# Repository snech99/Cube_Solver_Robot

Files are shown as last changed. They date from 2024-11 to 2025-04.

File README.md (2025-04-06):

# Cube_Solver_Robot

This work was created as part of a project in my mechatronics course at Hochschule Wismar, University of Applied Sciences: Technology, Business and Design. 
I worked on it together with a friend of mine. 

It's a Robot which can scan and solve a Rubik's Cube. It's possible to take out the Cube and twitch it by yourself. If you don't want to twist it by yourself, we have a mode which will turn it for you randomly with 20 moves. The Robot have two main modes: **Automatic and external_PC**.
Those modes are explained in a special PDF which you can find in the Repo.

The automatic mode solves the cube using an algorithm we wrote ourselves. It is based on the manual solution method, as a human would solve it.
This Code can be found under the following link: [Repo](https://github.com/snech99/Rubiks_Cube_Solver)

For external communication, the algorithm must be written by the user. There is a Python template for this, which communicates with the robot via a C program.
Download the folder /src/external_PC and compile the C program with make. You can then start the program as follows. You need the sudo privileges to be able to access the USB interface:

```bash
sudo ./main my_script
```

Here are some pictures to get an impression:

| Robot | Closeup of the colorsensor |
| --- | --- |
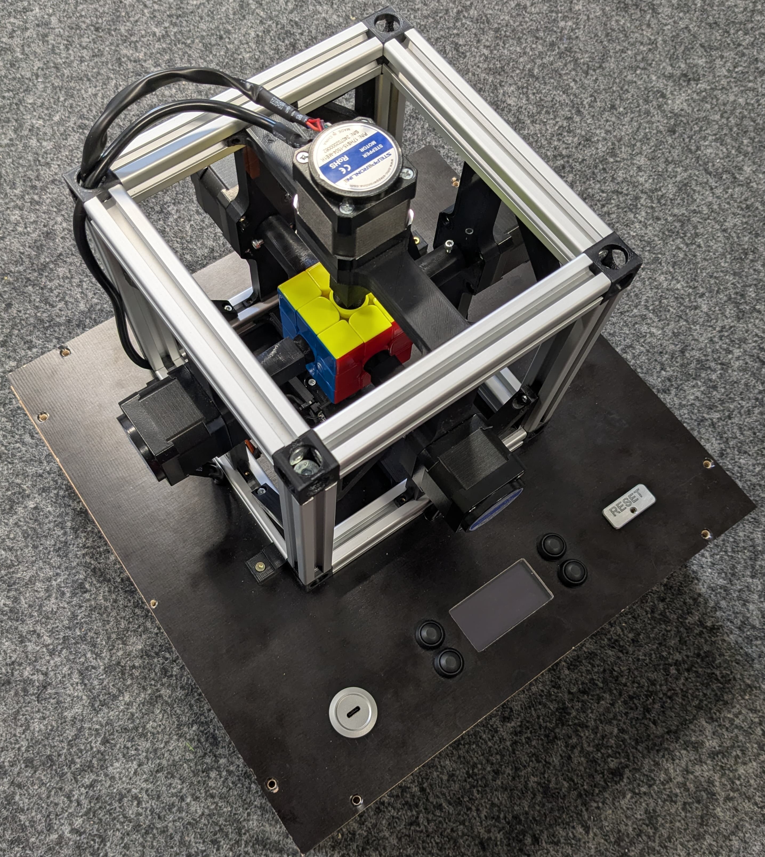
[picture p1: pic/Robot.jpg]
Robot
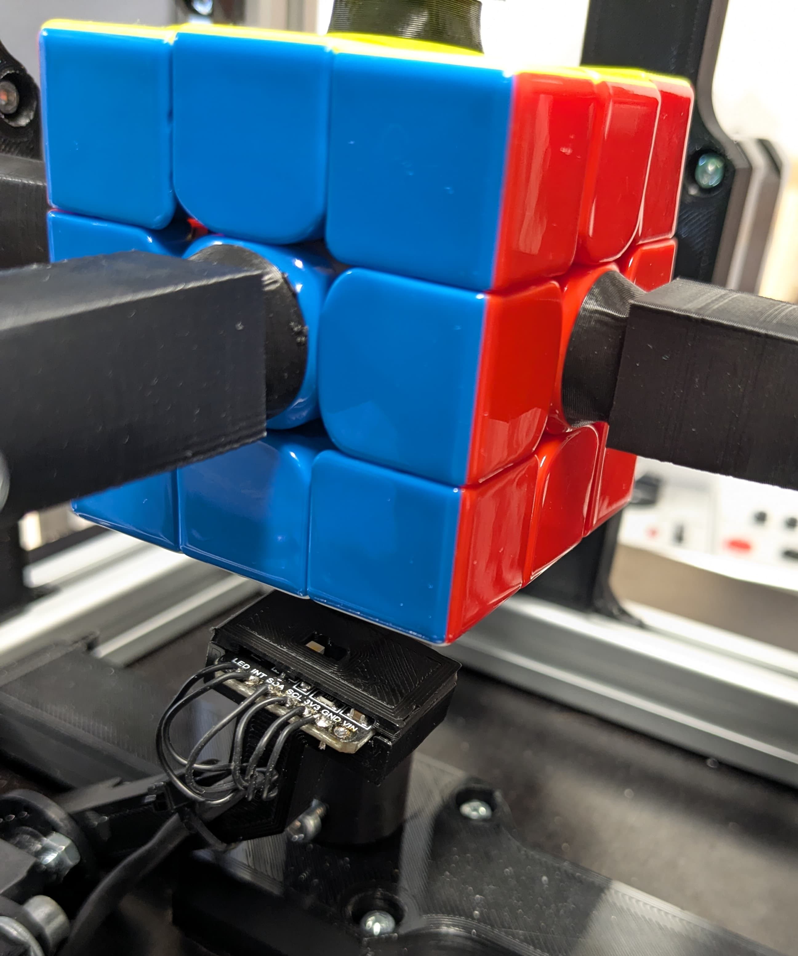
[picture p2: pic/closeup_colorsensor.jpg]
Closeup
|  |   |

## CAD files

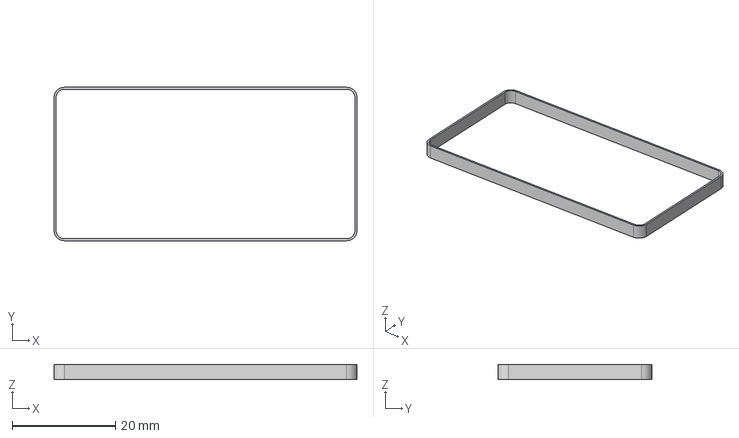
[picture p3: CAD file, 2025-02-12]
3D_Model/Einsatz Display v2.step
58.8 x 29.8 x 3.00 mm

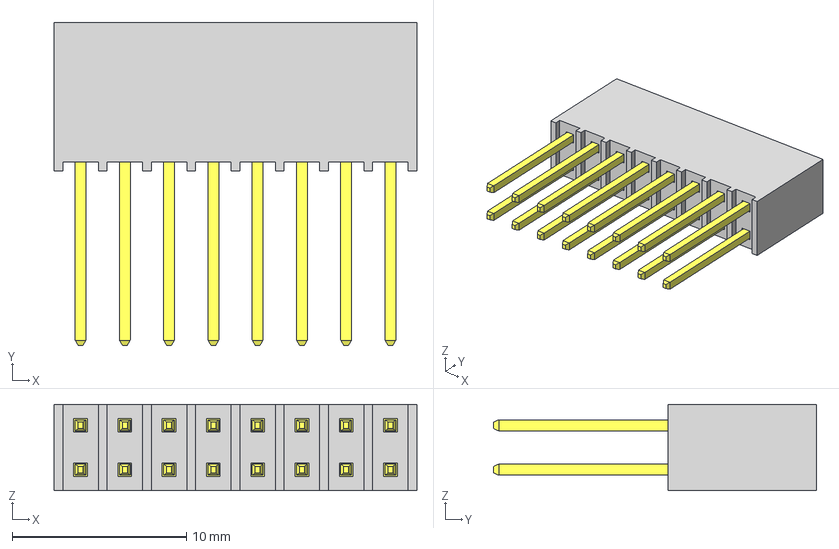
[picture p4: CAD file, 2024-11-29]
PCB/Solver_Shield/ALTIUM_EMBEDDED_MODELS/SSQ-108-03-T-D.stp
20.8 x 18.5 x 4.95 mm
T1SSQ-108-03-T-D
P2SSQ-108-03-T-D

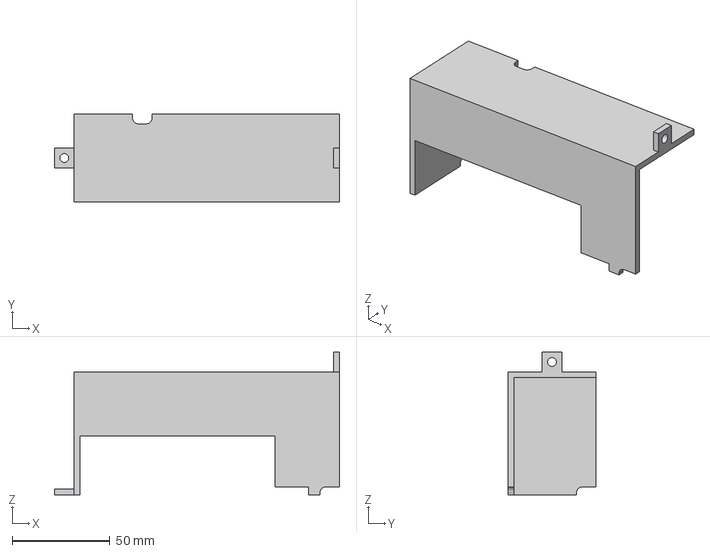
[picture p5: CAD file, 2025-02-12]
3D_Model/Abdeckung Netzteil klein v2.step
146.0 x 45.0 x 73.0 mm

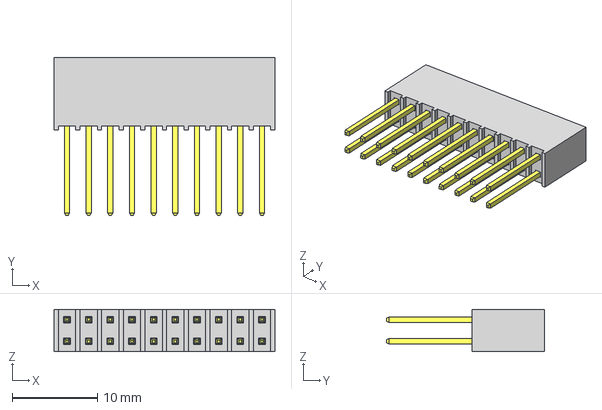
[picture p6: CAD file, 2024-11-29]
PCB/Solver_Shield/ALTIUM_EMBEDDED_MODELS/SSQ-110-03-T-D.stp
25.9 x 18.5 x 4.95 mm
T1SSQ-110-03-T-D
P2SSQ-110-03-T-D

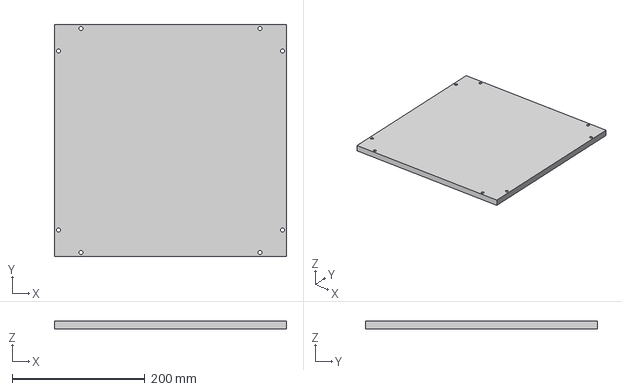
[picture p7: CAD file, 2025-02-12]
3D_Model/Boden v4.step
350.0 x 350.0 x 12.0 mm

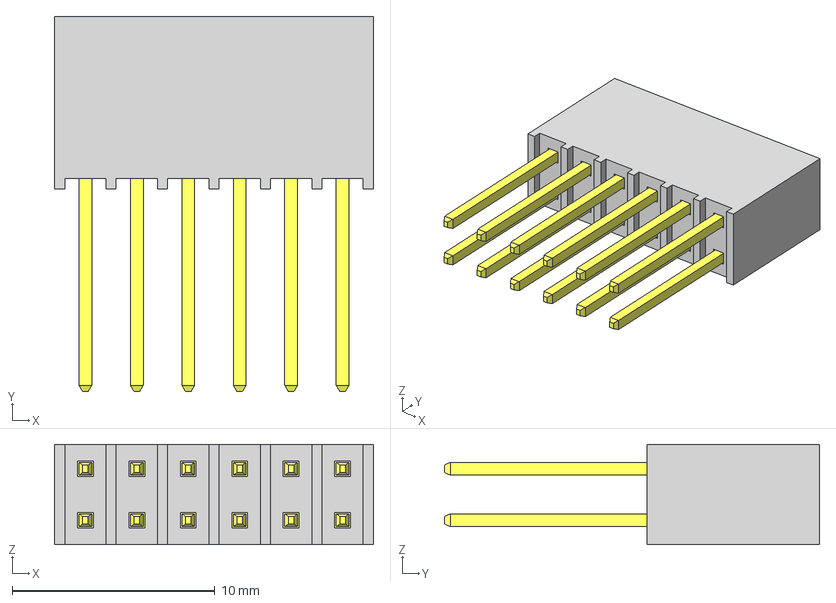
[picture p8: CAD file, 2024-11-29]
PCB/Solver_Shield/ALTIUM_EMBEDDED_MODELS/SSQ-106-03-T-D.stp
15.7 x 18.5 x 4.95 mm
T1SSQ-106-03-T-D
P2SSQ-106-03-T-D

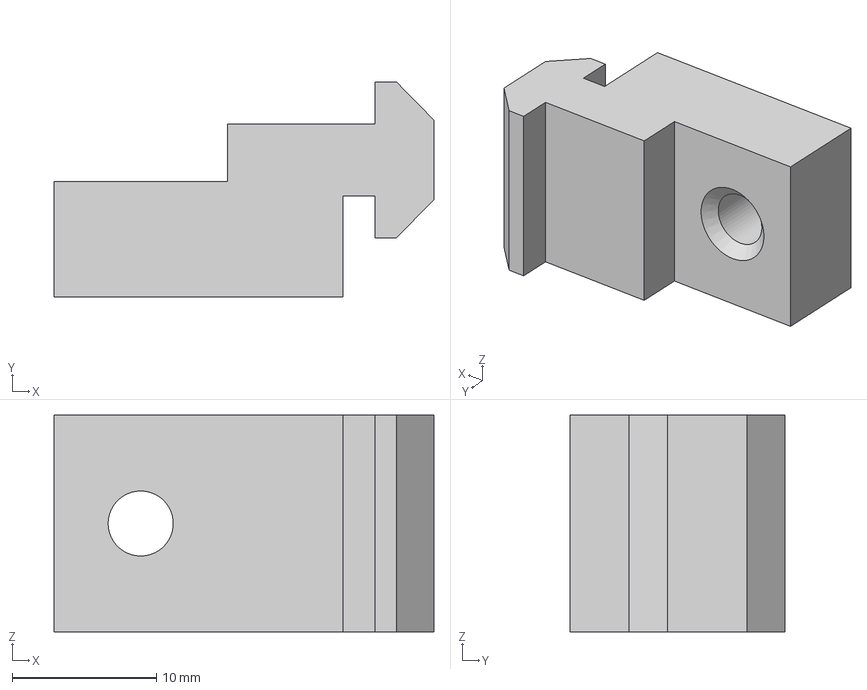
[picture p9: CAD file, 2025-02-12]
3D_Model/Halter Rahmen v5.step
26.3 x 14.9 x 15.0 mm

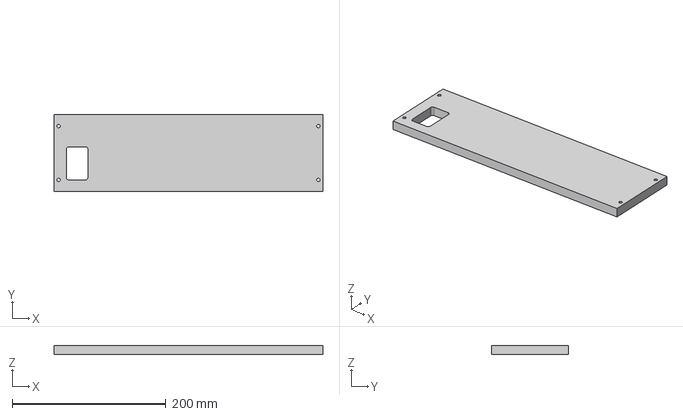
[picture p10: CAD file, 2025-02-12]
3D_Model/Wand hinten v6.step
350.0 x 100.0 x 12.0 mm

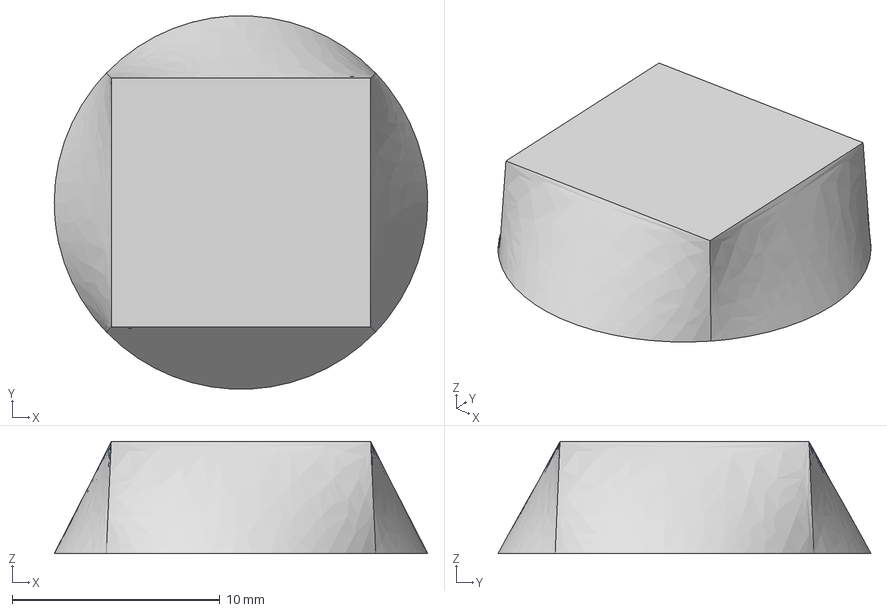
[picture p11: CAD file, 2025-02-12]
3D_Model/Halter Magnete Würfel v2.step
18.0 x 18.0 x 5.40 mm

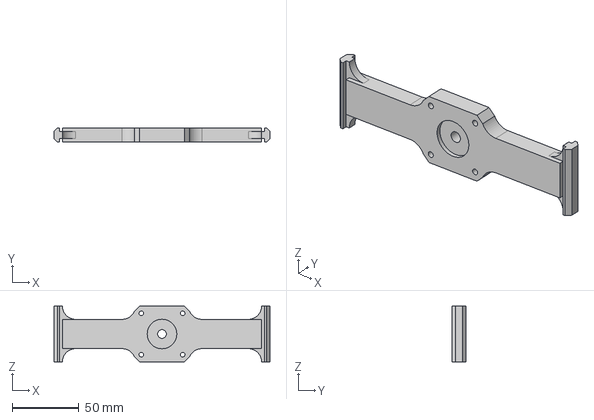
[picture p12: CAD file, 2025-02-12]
3D_Model/Halter Motor v26.step
162.2 x 10.8 x 42.0 mm

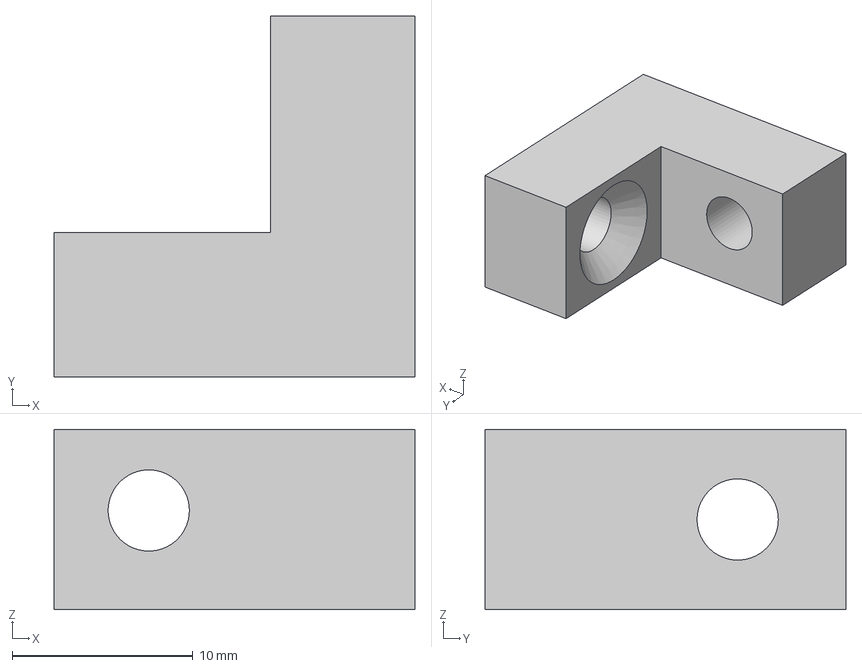
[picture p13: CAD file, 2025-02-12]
3D_Model/Halter Servo v4.step
20.0 x 20.0 x 10.0 mm

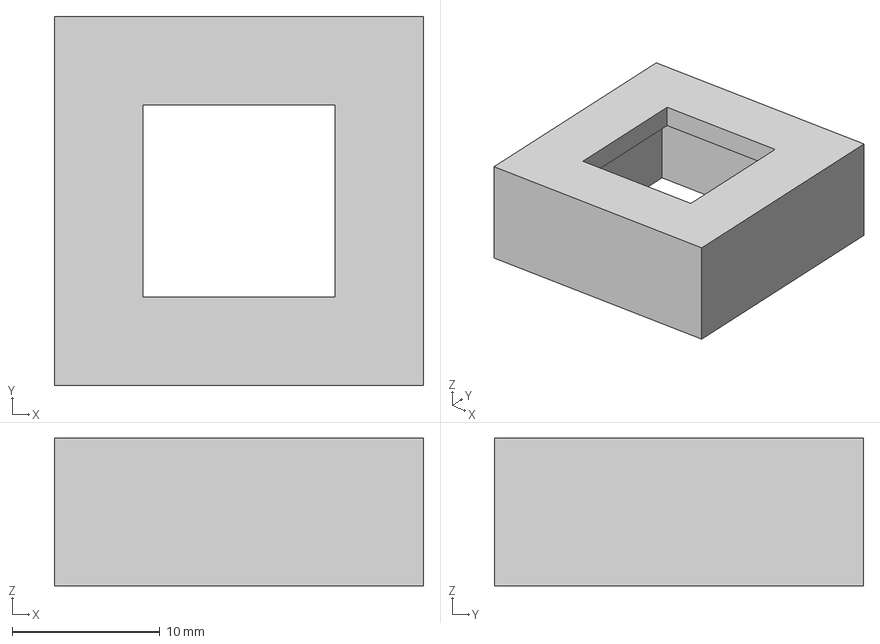
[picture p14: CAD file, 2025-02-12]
3D_Model/Klebehilfe Magnete v5.step
25.0 x 25.0 x 10.0 mm

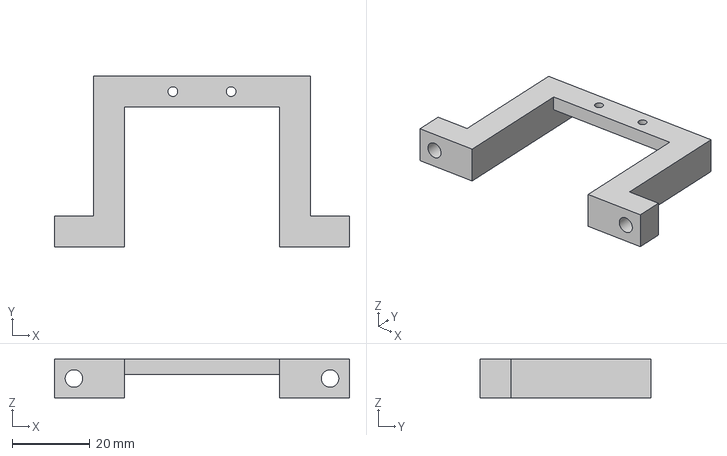
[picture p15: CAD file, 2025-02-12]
3D_Model/Halter USB v1.step
76.0 x 44.0 x 10.0 mm

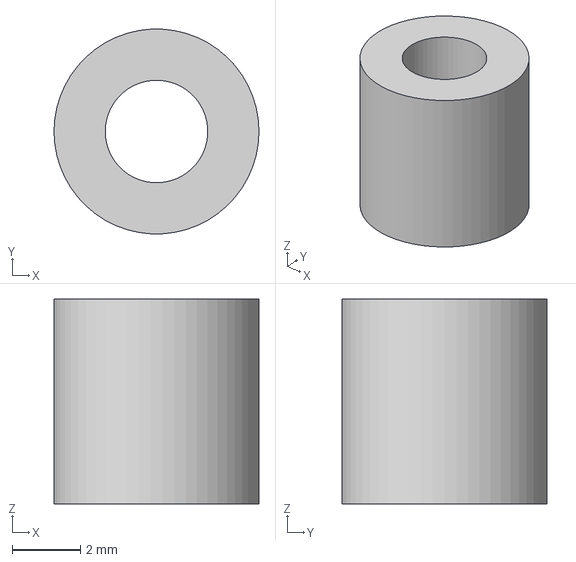
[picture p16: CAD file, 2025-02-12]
3D_Model/Abstandshalter Stepdownwandler v2.step
6.00 x 5.99 x 6.00 mm

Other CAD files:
3D_Model/Deckel v22.step
3D_Model/Deckel ohne USB v4.step
3D_Model/Wand vorne v4.step
3D_Model/Halter Magnete v10.step
3D_Model/Abdeckung Netzteil v5.step
3D_Model/Abdeckung Sensor v7.step
3D_Model/Abstandshalter Display v2.step
3D_Model/Ecke Aluprofil v8.step
3D_Model/Halter Reset v3.step
3D_Model/Halter Reset v4.step
3D_Model/Reset Griff v1.step
3D_Model/Schild v3.step
3D_Model/Sensorarm v34.step
3D_Model/Versteifung v2.step
3D_Model/Wand links_rechts v6.step

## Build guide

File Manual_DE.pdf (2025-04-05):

# Manual Cube_Solver_Robot

## Inhalt

## Hardware

- Sechs Schrittmotoren im Closed-Loop System: Nema 17HS15-1504-ME1K
- Sechs Closed-Loop Schrittmotortreiber: CL42T-V41
- Servo Motor: RS2
- FRDM-MCXA153 Development Board (MCUXpresso IDE)
- Farbsensor: TCS34725 RGB
- Würfel: QiYi M Pro 3x3 MagLev Ball-Core UV Coated (Achtung nicht jeder Würfel ist geeignet)
- OLED-Bildschirm: SSD1309
- 5 Taster
- Netzteil 24V: S-250-25
- Stepdown-Wandler: LM2596 (für Lüfter)
- Stepdown-Wandler: ICQUANZX DC DC 9A 300W (für 5V Netz)
- 4 Lüfter: SUN MF80252V3-1
- 48 Neodym 5x5x5mm
- Selbstentwickelte Platine
- USB-C Buchse und Konverter: CP2102
- Kaltgeräte Buchse und Kabel: 693-4302.2001

## Würfel tauschen

Der Würfel ist über Magnete mit den Motoren verbunden. Dafür muss dieser jedoch leicht modifiziert werden, dafür wurden an jeder Seite des Würfels vier kleine Magnete verklebt. Dabei ist die Ausrichtung der Magnete zu beachten. Sie sind alle in einem Nord-Süd Wechsel angebracht. Dies ist ebenfalls beim Einbauen des Würfels zu beachten und es müssen ggf. Motoren um 90° gedreht werden, damit die Magnete des Würfels und der Motoren passend übereinstimmen.

ACHTUNG:
Beim Einsetzten MUSS die Gelbe Fläche nach oben und die Rote Fläche nach vorne zeigen!

Der Würfel ist frei entnehmbar und sollte entweder vor dem Anschalten des Roboters eingesetzt werden oder in dem dafür vorgesehenen Modus: „Change Cube“.

Wichtig ist, dass sich der Roboter nach dem Einschalten und in dem oben genannten Modus kalibriert. Daher ist es wichtig, dass der Würfel annähernd passend und nicht verkanntet eingesetzt wird.

## Reset

Falls sich der Roboter aufhängen sollte gibt es auch einen Reset Knopf, welcher mit einem passenden Stift betätigt werden kann. Auch hier wird sich der Roboter neu kalibrieren. Außerdem wird der Kontroller zurückgesetzt und verliert jegliche gespeicherte Informationen.

## Zustands Automat

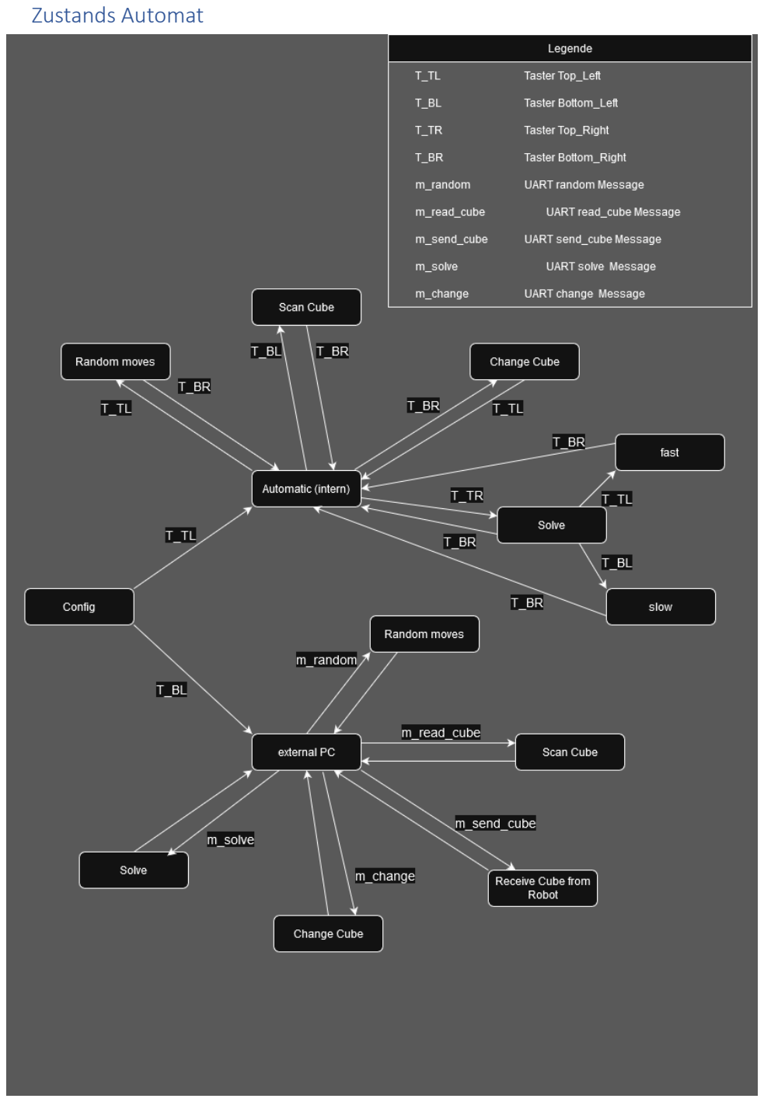
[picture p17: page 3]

## Allgemeine Funktionen und Modi

Der Roboter verfügt über zwei Hauptmodi: Automatic und external_PC

Die Funktionen des Roboters sind dabei sehr ähnlich, jedoch ändert sich die Bedienung. In dem Automatic- Modus wird der Roboter über vier Taster und den Bildschirm gesteuert. Bei dem external_PC- Modus läuft diese Bedienung über die USB-Schnittstelle. Diese Auswahl muss nach dem Anschalten des Roboters über Taster ausgewählt werden. Für den external_PC-Modus existiert im /src/external_Computer Ordner eine Datei für die Kommunikation.

### Funktionen im Automatic-Modus

Random moves
In dieser Funktion verdreht der Roboter zufällig 20 Seiten nacheinander. Der „Zufall“ wird hier über eine interne rand() Funktion gelöst, welchen den aktuellen Systemtick des Kontrollers als Seed nutzt.

Change Cube
Hier werden alle Motoren deaktiviert und der Würfel kann entnommen und/oder eingesetzt werden.

Nach dem Tauschen muss ein Taster auf dem Roboter gedrückt werden, um den Wechsel zu bestätigen. Im Folgenden kalibrieren sich alle Seiten wieder nacheinander und der Roboter ist erneut einsatzbereit.

Scan Cube
In dieser Funktion wird der Würfel eingelesen. Dafür wird jede Fläche nacheinander von einem Farbsensor gelesen dann interpretiert und abgespeichert. Um alle Flächen auf die untere Seite zu bekommen wird eine bestimmte Zugabfolge genutzt, welche den Würfel nicht verändert. Somit ist am Ende nach ca. 35 Sekunden der gesamte Würfel eingelesen und wurde dennoch nicht verändert.

Die einzelnen Steine werden nach einem bestimmten System in einem Array abgespeichert, welches später genauer erläutert wird.

Solve
Hier löst ein von uns selbst geschriebener Algorithmus den eingelesenen Würfel und speichert die benötigten Züge in ein Array auf dem Kontroller ab. Dieser Algorithmus ist auf der GitHub Seite des Repo verlinkt.

Fast/Slow
In diesen Funktionen wird das in Solve berechnete Lösungsarray mit der entsprechenden Geschwindigkeit ausgeführt. Nach dem Erfolgreichen Lösen des Würfels werden die benötigten Züge und Zeit auf dem Bildschirm angezeigt.

### Funktionen im external_PC-Modus

Random moves
In dieser Funktion verdreht der Roboter zufällig 20 Seiten nacheinander. Der „Zufall“ wird hier über eine interne rand() Funktion gelöst, welchen den aktuellen Systemtick des Kontrollers als Seed nutzt.

Change Cube
Hier werden alle Motoren deaktiviert und der Würfel kann entnommen und/oder eingesetzt werden.

Nach dem Tauschen muss ein Taster auf dem Roboter gedrückt werden, um den Wechsel zu bestätigen. Im Folgenden kalibrieren sich alle Seiten wieder nacheinander und der Roboter ist wieder einsatzbereit.

Scan Cube
In dieser Funktion wird der Würfel eingelesen. Dafür wird jede Fläche nacheinander von einem Farbsensor gelesen dann interpretiert und abgespeichert. Um alle Flächen auf die untere Seite zu bekommen wird eine bestimmte Zugabfolge genutzt, welche den Würfel nicht verändert. Somit ist am Ende nach ca. 35 Sekunden der gesamte Würfel eingelesen und wurde dennoch nicht verändert.

Die einzelnen Steine werden nach einem bestimmten System in einem Array abgespeichert, welches später genauer erläutert wird.

Receive Cube from Robot
Hier wird der eingelesene Würfel vom Roboter über die USB-Schnittstelle an den externen PC gesendet und dort abgespeichert.

Wichtig: In den externen Bedienoptionen gibt es noch zwei weitere Funktionen, welche nicht auf dem Bild des Zustands Automaten oben aufgeführt sind.

Show Cube

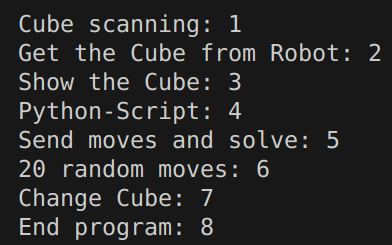
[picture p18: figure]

In dieser Funktion wird der zuletzt Empfangene Würfen im Terminal ausgegeben.

Python-Skript
Hier wird vom C Programm über die Funktion fork() ein Python-Skript ausgeführt. Dieses berechnet dann die benötigten Züge, um den Würfel zu lösen. Die Kommunikation zwischen dem C Programm und dem Python Skript wird über Inter-Prozess-Communication (IPC) realisiert.

Passend dafür existiert im /src/external_Computer Ordner eine Vorlage in welcher nur noch der eigene Lösungsalgorithmus implementiert werden muss. In dieser Vorlage wird der Würfel aus dem C Programm eingelesen und am Ende das Lösungsarray mit maximal 1024 Züge zurück an das C Programm gesendet.

Solve
In dieser Funktion wird das aus dem Python-Skript berechnete Lösungsarray an den Kontroller geschickt und dort auch sofort ausgeführt. Am Ende werden die benötigten Züge und die Zeit auf dem Bildschirm angezeigt.

## Darstellung des Würfels für den external_PC-Modus

Jede Farbe ist einer Zahl zugeordnet:

Das eingelesene Array besteht aus 54 Zahlen und jede repräsentiert eine farbige Seite eines Steins auf dem Würfel. Das Array besteht so theoretisch aus 6 Blöcken, welche jeweils eine Fläche darstellen. Jeder dieser Blöcke beinhaltet 9 Zahlen. Die Reihenfolge der eingelesenen Blöcke ist:

Weiß -> Rot -> Blau-> Orange -> Grün -> Gelb

Jeder Stein auf dieser Fläche wird dabei nach dem folgenden Muster eingelesen:

Farbe | Nummer
Weiß | 1
Gelb | 2
Rot | 3
Grün | 4
Orange | 5
Blau | 6

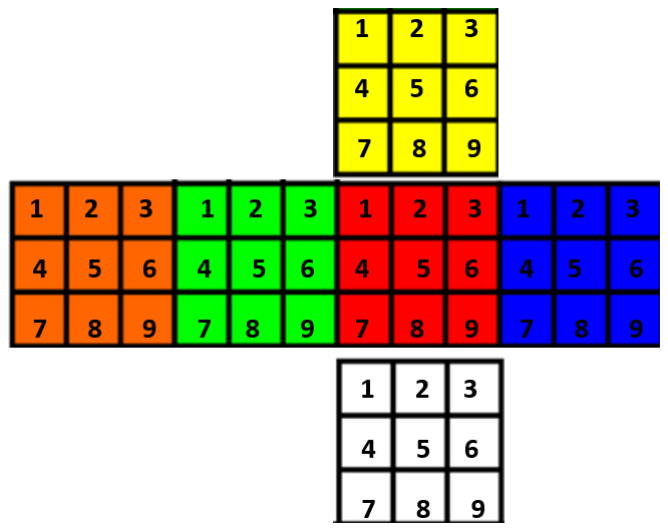
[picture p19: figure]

Würfel = [

W1, W2, W3, W4, W5, W6, W7, W8, W9,

R1, R2, R3, R4, R5, R6, R7, R8, R9,

B1, B2, B3, B4, B5, B6, B7, B8, B9,

O1, O2, O3, O4, O5, O6, O7, O8, O9,

G1, G2, G3, G4, G5, G6, G7, G8, G9,

Y1, Y2, Y3, Y4, Y5, Y6, Y7, Y8, Y9

]

Tipp: Die Zahlen an der Position 5 des Blockes repräsentieren die Farbe der Fläche, da sich die Mittelsteine nicht verschieben lassen!

## Darstellung der Drehungen für den external_PC-Modus

Jede Drehung ist mit folgenden Zahlen codiert (Genormte Notation als Vergleich).

Rechts beschreibt die Drehung im Uhrzeigersinn und Links die gegen den Uhrzeigersinn.

Das Ergebnisarray, welches an den Roboter geschickt wird, darf somit nur Zahlen zwischen 1 und 12 oder 21 und 26 beinhalten. Außerdem ist die Länge auf 1024 Züge begrenzt.

## Software

Für Änderungen in der Software ist der Code für den Mikrocontroller ebenfalls mit im Repo. Zu beachten sind hier die #defines in der Cube_Project.h, welche für den jeweils verwendetet Roboter einzustellen sind, da sich die beiden Modelle doch etwas unterscheiden.

Diese Unterschiede sind in der Kalibrierung der Achsen und des Farbsensors zu beachten und gegebenenfalls anzupassen.

Seite | Rechts | Links | Doppel | Notation
Weiß | 1 | D | 7 | D‘ | 21 | D2 | Down
Gelb | 2 | U | 8 | U‘ | 22 | U2 | Up
Rot | 3 | F | 9 | F‘ | 23 | F2 | Front
Grün | 4 | R | 10 | R‘ | 24 | R2 | Right
Orange | 5 | B | 11 | B‘ | 25 | B2 | Back
Blau | 6 | L | 12 | L‘ | 26 | L2 | Left

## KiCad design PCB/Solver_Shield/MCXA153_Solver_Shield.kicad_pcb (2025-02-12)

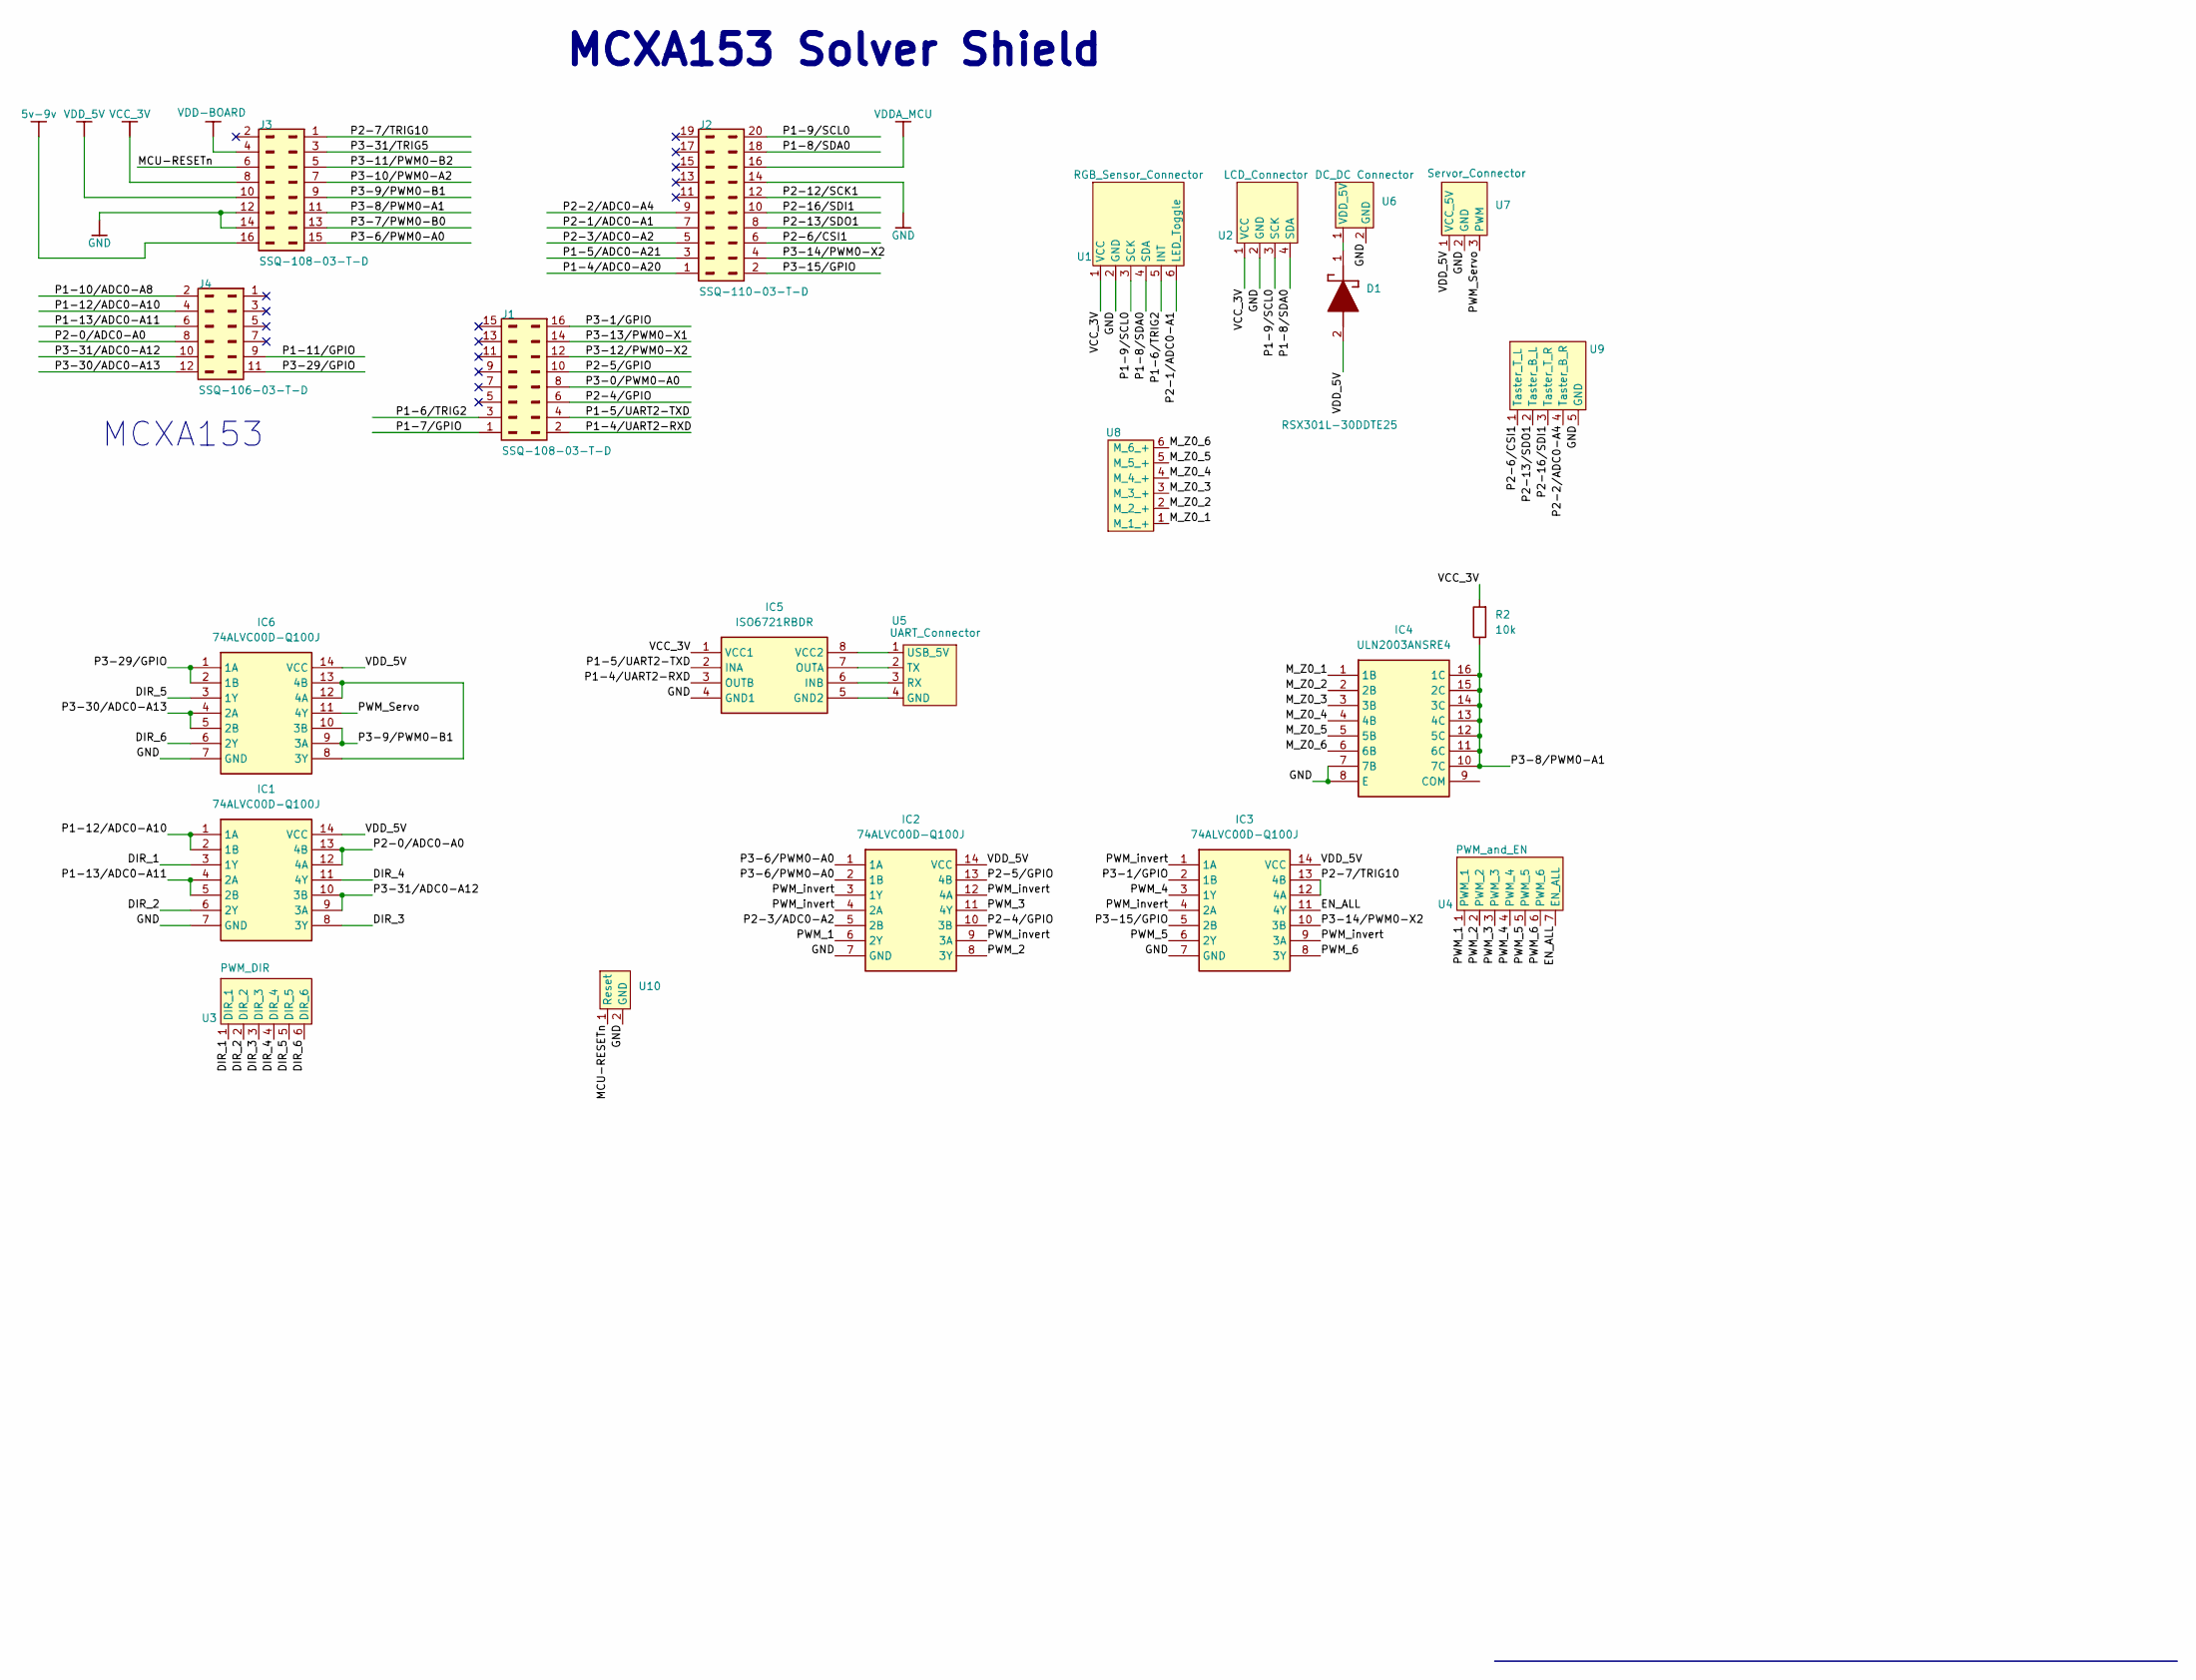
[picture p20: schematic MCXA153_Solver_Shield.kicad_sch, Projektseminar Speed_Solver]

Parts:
D1: RSX301L-30DDTE25; DIOM5026X220N; Mouser Part Number 755-RSX301L-30DDTE25
IC1, IC2, IC3, IC6: 74ALVC00D-Q100J; SOIC127P600X175-14N; Mouser Part Number 771-74ALVC00DQ100J
IC4: ULN2003ANSRE4; SOIC127P780X200-16N; Mouser Part Number 595-ULN2003ANSRE4
IC5: ISO6721RBDR; SOIC127P600X175-8N; Mouser Part Number 595-ISO6721RBDR
J1, J3: SSQ-108-03-T-D; MANUFACTURER PART NUMBER SSQ-108-03-T-D
J2: SSQ-110-03-T-D; MANUFACTURER PART NUMBER SSQ-110-03-T-D
J4: SSQ-106-03-T-D; MANUFACTURER PART NUMBER SSQ-106-03-T-D
R2: 10k; R_0603_1608Metric_Pad0.98x0.95mm_HandSolder
U1: Pinheader_Sensor
U2: Pinheader_LCD
U3: PWM_DIR
U4: Treiber_PWM
U5: UART
U6: VDD_5V
U7: Servo
U8: Z0
U9: Taster
U10: Reset_Connector

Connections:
5v-9v: J3.16
/DIR_1: IC1.3 (1Y), U3.1 (DIR)
/DIR_2: IC1.6 (2Y), U3.2 (DIR)
/DIR_3: IC1.8 (3Y), U3.3 (DIR)
/DIR_4: IC1.11 (4Y), U3.4 (DIR)
/DIR_5: IC6.3 (1Y), U3.5 (DIR)
/DIR_6: IC6.6 (2Y), U3.6 (DIR)
/EN_ALL: IC3.11 (4Y), U4.7 (EN_ALL)
/MCU-RESETn: J3.6, U10.1 (Reset)
/M_Z0_1: IC4.1 (1B), U8.1 (M_1_+)
/M_Z0_2: IC4.2 (2B), U8.2 (M_2_+)
/M_Z0_3: IC4.3 (3B), U8.3 (M_3_+)
/M_Z0_4: IC4.4 (4B), U8.4 (M_4_+)
/M_Z0_5: IC4.5 (5B), U8.5 (M_5_+)
/M_Z0_6: IC4.6 (6B), U8.6 (M_6_+)
/P1-4/ADC0-A20: J2.1
/P1-4/UART2-RXD: IC5.3 (OUTB), J1.2
/P1-5/ADC0-A21: J2.3
/P1-5/UART2-TXD: IC5.2 (INA), J1.4
/P1-6/TRIG2: J1.3, U1.5 (INT)
/P1-7/GPIO: J1.1
/P1-8/SDA0: J2.18, U1.4 (SDA), U2.4 (SDA)
/P1-9/SCL0: J2.20, U1.3 (SCK), U2.3 (SCK)
/P1-10/ADC0-A8: J4.2
/P1-11/GPIO: J4.9
/P1-12/ADC0-A10: IC1.1 (1A), IC1.2 (1B), J4.4
/P1-13/ADC0-A11: IC1.4 (2A), IC1.5 (2B), J4.6
/P2-0/ADC0-A0: IC1.12 (4A), IC1.13 (4B), J4.8
/P2-1/ADC0-A1: J2.7, U1.6 (LED_Toggle)
/P2-2/ADC0-A4: J2.9, U9.4 (Taster_B_R)
/P2-3/ADC0-A2: IC2.5 (2B), J2.5
/P2-4/GPIO: IC2.10 (3B), J1.6
/P2-5/GPIO: IC2.13 (4B), J1.10
/P2-6/CSI1: J2.6, U9.1 (Taster_T_L)
/P2-7/TRIG10: IC3.12 (4A), IC3.13 (4B), J3.1
/P2-12/SCK1: J2.12
/P2-13/SDO1: J2.8, U9.2 (Taster_B_L)
/P2-16/SDI1: J2.10, U9.3 (Taster_T_R)
/P3-0/PWM0-A0: J1.8
/P3-1/GPIO: IC3.2 (1B), J1.16
/P3-6/PWM0-A0: IC2.1 (1A), IC2.2 (1B), J3.15
/P3-7/PWM0-B0: J3.13
/P3-8/PWM0-A1: IC4.10 (7C), IC4.11 (6C), IC4.12 (5C), IC4.13 (4C), IC4.14 (3C), IC4.15 (2C), IC4.16 (1C), J3.11, R2.1
/P3-9/PWM0-B1: IC6.9 (3A), IC6.10 (3B), J3.9
/P3-10/PWM0-A2: J3.7
/P3-11/PWM0-B2: J3.5
/P3-12/PWM0-X2: J1.12
/P3-13/PWM0-X1: J1.14
/P3-14/PWM0-X2: IC3.10 (3B), J2.4
/P3-15/GPIO: IC3.5 (2B), J2.2
/P3-29/GPIO: IC6.1 (1A), IC6.2 (1B), J4.11
/P3-30/ADC0-A13: IC6.4 (2A), IC6.5 (2B), J4.12
/P3-31/ADC0-A12: IC1.9 (3A), IC1.10 (3B), J4.10
/P3-31/TRIG5: J3.3
/PWM_1: IC2.6 (2Y), U4.1 (PWM_1)
/PWM_2: IC2.8 (3Y), U4.2 (PWM_2)
/PWM_3: IC2.11 (4Y), U4.3 (PWM_3)
/PWM_4: IC3.3 (1Y), U4.4 (PWM_4)
/PWM_5: IC3.6 (2Y), U4.5 (PWM_5)
/PWM_6: IC3.8 (3Y), U4.6 (PWM_6)
/PWM_Servo: IC6.11 (4Y), U7.3 (PWM)
/PWM_invert: IC2.3 (1Y), IC2.4 (2A), IC2.9 (3A), IC2.12 (4A), IC3.1 (1A), IC3.4 (2A), IC3.9 (3A)
GND: IC1.7 (GND), IC2.7 (GND), IC3.7 (GND), IC4.7 (7B), IC4.8 (E), IC5.4 (GND1), IC6.7 (GND), J2.14, J3.12, J3.14, U1.2 (GND), U2.2 (GND), U6.2 (GND), U7.2 (GND), U9.5 (GND), U10.2 (GND)
unnamed: D1.1 (K), U6.1 (VDD_5V)
unnamed: IC5.5 (GND2), U5.4 (GND)
unnamed: IC5.6 (INB), U5.3 (RX)
unnamed: IC5.7 (OUTA), U5.2 (TX)
unnamed: IC5.8 (VCC2), U5.1 (USB_5V)
unnamed: IC6.8 (3Y), IC6.12 (4A), IC6.13 (4B)
VCC_3V: IC5.1 (VCC1), J3.8, R2.2, U1.1 (VCC), U2.1 (VCC)
VDD-BOARD: J3.4
VDDA_MCU: J2.16
VDD_5V: D1.2 (A), IC1.14 (VCC), IC2.14 (VCC), IC3.14 (VCC), IC6.14 (VCC), J3.10, U7.1 (VCC_5V)

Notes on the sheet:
MCXA153 Solver Shield
MCXA153

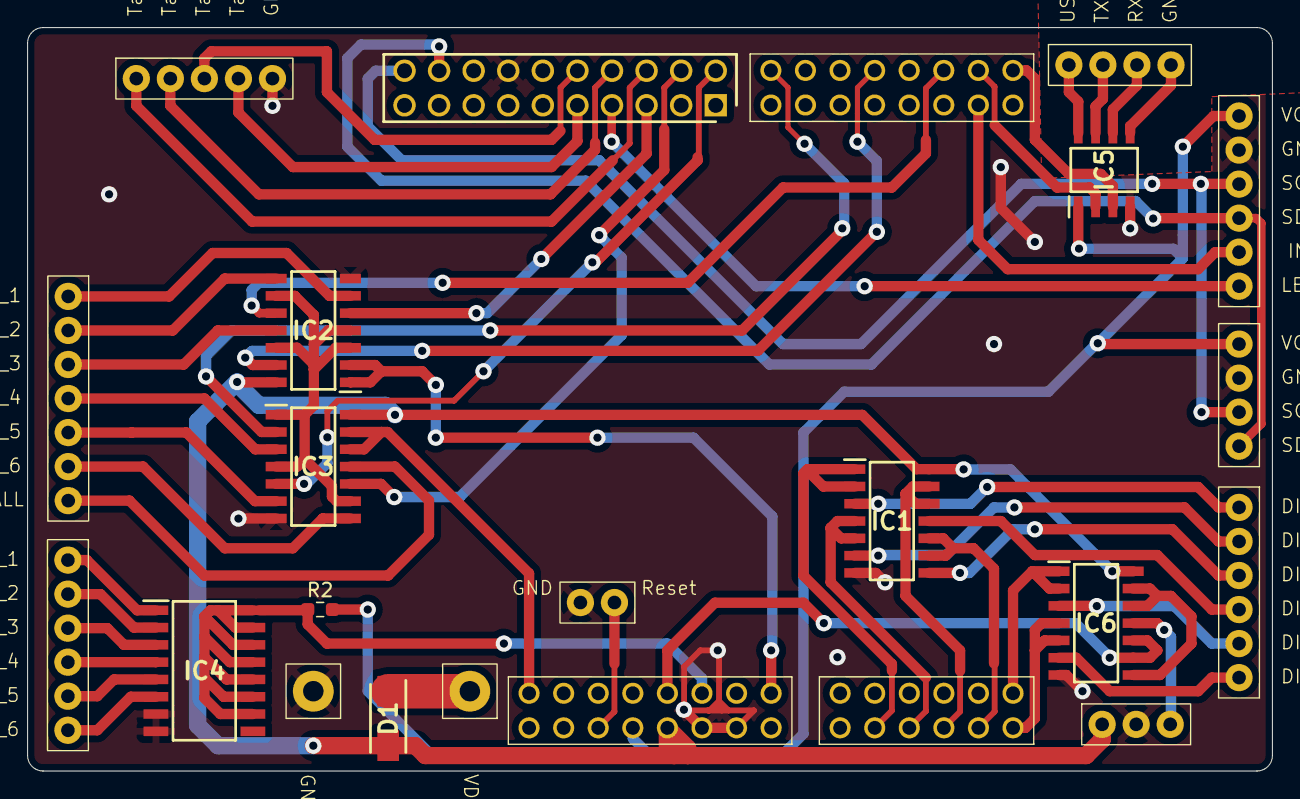
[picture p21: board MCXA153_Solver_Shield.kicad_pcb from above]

Board: 2 copper layers, 91.4 x 54.6 mm, 22 parts (0 on the bottom side), 57 nets.

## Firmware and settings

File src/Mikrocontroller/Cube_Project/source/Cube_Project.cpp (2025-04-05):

/*
*   Gerrit Hinrichs 01.2025
*   github.com/snech99
*
*   Cube_Solver_Robot
*   main file for the Controller with super-loop
*/
#include <stdio.h>
#include <stdlib.h>
#include "board.h"
#include "clock_config.h"
#include "MCXA153.h"

#include "Cube_Project.h"
#include "state_machine.h"

uint8_t rx_buffer[BUFFER_MAX] = {};
uint16_t rx_buffer_index = 0;

bool flag_hit_1 = false;
bool flag_hit_2 = false;
bool SW_hit_flag = false;
bool SW_flag_TL = false;
bool SW_flag_TR = false;
bool SW_flag_BL = false;
bool SW_flag_BR = false;
bool color_busy_flag = true;
bool pwm_busy_flag = false;
bool pwm_servo_busy_flag = false;
bool NULL_flag = false;

uint32_t tick_count = 0;
uint32_t tick_start = 0;
uint32_t tick_end = 0;

volatile uint32_t pwm_ms_count = 0;
volatile int32_t PWM_flanke_count = 250;
volatile uint32_t PWM_frequenz = PWM_FREQUENZ;
volatile uint32_t PWM_ramp_time = RAMP_LONG;

// Timer for PWM-Ramp
void TIMER1_CALLBACK_RAMPE(uint32_t flags)
{
	if (pwm_ms_count < (PWM_ramp_time-1))
	{
		float add_frequenz = (float)PWM_frequenz/PWM_ramp_time;
		uint32_t new_frequenz = (uint32_t) add_frequenz + (pwm_ms_count*add_frequenz);

		if(new_frequenz == 0)
		{
			new_frequenz = 1;
		}
		pwm_ms_count++;

		PWM_SetupPwm(FLEXPWM0_PERIPHERAL, FLEXPWM0_ALL_PWM, FLEXPWM0_ALL_PWM_pwm_function_config, 1U, kPWM_SignedCenterAligned,
				new_frequenz, FLEXPWM0_ALL_PWM_SM_CLK_SOURCE_FREQ_HZ);

		FLEXPWM0_PERIPHERAL->MCTRL |= PWM_MCTRL_LDOK(kPWM_Control_Module_0);
	}
	else
	{
		if(PWM_frequenz == 0)
		{
			PWM_frequenz = 1;
		}

		PWM_SetupPwm(FLEXPWM0_PERIPHERAL, FLEXPWM0_ALL_PWM, FLEXPWM0_ALL_PWM_pwm_function_config, 1U, kPWM_SignedCenterAligned,
				PWM_frequenz, FLEXPWM0_ALL_PWM_SM_CLK_SOURCE_FREQ_HZ);


		FLEXPWM0_PERIPHERAL->MCTRL |= PWM_MCTRL_LDOK(kPWM_Control_Module_0);
		CTIMER_StopTimer(CTIMER1);
	}
}

// Timer to debounce the buttons
void TIMER0_ISR_RESET_CALLBACK(uint32_t flags)
{
	if(GPIO_PinRead(GPIO2, TASTER_T_L) == 0)
	{
		SW_flag_TL = true;
	}

	if(GPIO_PinRead(GPIO2, TASTER_T_R) == 0)
	{
		SW_flag_TR = true;
	}

	if(GPIO_PinRead(GPIO2, TASTER_B_L) == 0)
	{
		SW_flag_BL = true;
	}

	if(GPIO_PinRead(GPIO2, TASTER_B_R) == 0)
	{
		SW_flag_BR = true;
	}

	GPIO_GpioClearInterruptFlags(GPIO2, 1<<TASTER_T_L);
	GPIO_GpioClearInterruptFlags(GPIO2, 1<<TASTER_T_R);
	GPIO_GpioClearInterruptFlags(GPIO2, 1<<TASTER_B_L);
	GPIO_GpioClearInterruptFlags(GPIO2, 1<<TASTER_B_R);

	CTIMER_StopTimer(CTIMER0);
	EnableIRQ(GPIO2_IRQN);
}

// General delay Timer
void Busy_Timer(uint32_t flags)
{
	pwm_servo_busy_flag = false;
	pwm_busy_flag = false;
}

/* FLEXPWM0_SUBMODULE0_IRQn interrupt handler */
extern "C" void INTERRUPT_PWM(void)
{
	if (PWM_GetStatusFlags(FLEXPWM0_PERIPHERAL, kPWM_Module_0) & kPWM_CompareVal2Flag)
	{
		PWM_flanke_count--;
		if(PWM_flanke_count <= 0)
		{
			FLEXPWM0_PERIPHERAL->MCTRL &= ~(PWM_MCTRL_RUN(kPWM_Control_Module_0));
			CTIMER_StartTimer(CTIMER2);
		}
	}
	PWM_ClearStatusFlags(FLEXPWM0_PERIPHERAL, kPWM_Module_0, kPWM_CompareVal2Flag);
}


/* LPUART0_IRQn interrupt handler */
extern "C" void LPUART2_SERIAL_RX_TX_IRQHANDLER(void)
{
	uint8_t data;
	uint32_t status= LPUART_GetStatusFlags(LPUART2_PERIPHERAL);

	if ( (status & kLPUART_RxDataRegFullFlag) )
	{
		data = LPUART_ReadByte(LPUART2_PERIPHERAL);

		if(rx_buffer_index < BUFFER_MAX)
		{
			rx_buffer[rx_buffer_index] = data;
			rx_buffer_index ++;
		}
		else
		{
			GPIO_PinWrite(BOARD_LED_RED_GPIO, 12, 0);
			GPIO_PinWrite(BOARD_LED_GREEN_GPIO, 13, 1);
			GPIO_PinWrite(BOARD_LED_BLUE_GPIO, 0, 0);
		}

		if(data == '$')
		{
			flag_hit_1 = true;
		}

		if((data == '%') && flag_hit_1)
		{
			flag_hit_2 = true;
		}
	}
	LPUART_ClearStatusFlags(LPUART2_PERIPHERAL, kLPUART_RxDataRegFullFlag);
}

/* GPIO1_IRQn interrupt handler */
extern "C" void GPIO1_IRQHANDLER(void)
{
	uint32_t hit_flag = GPIO_GpioGetInterruptFlags(GPIO1);

	if((hit_flag>>INTERUPT_SENSOR_PIN) == 1)
	{
		color_busy_flag = false;
	}

	GPIO_GpioClearInterruptFlags(GPIO1, 1<<INTERUPT_SENSOR_PIN);
}

// IRQN for the Buttons
extern "C" void GPIO2_IRQHANDLER(void)
{
	uint32_t hit_flag = GPIO_GpioGetInterruptFlags(GPIO2);

	if((hit_flag>>TASTER_T_L) == 1)
	{
		DisableIRQ(GPIO2_IRQN);
		CTIMER_StartTimer(CTIMER0);
	}

	if((hit_flag>>TASTER_T_R) == 1)
	{
		DisableIRQ(GPIO2_IRQN);
		CTIMER_StartTimer(CTIMER0);
	}

	if((hit_flag>>TASTER_B_L) == 1)
	{
		DisableIRQ(GPIO2_IRQN);
		CTIMER_StartTimer(CTIMER0);
	}

	if((hit_flag>>TASTER_B_R) == 1)
	{
		DisableIRQ(GPIO2_IRQN);
		CTIMER_StartTimer(CTIMER0);
	}

	GPIO_GpioClearInterruptFlags(GPIO2, 1<<TASTER_T_L);
	GPIO_GpioClearInterruptFlags(GPIO2, 1<<TASTER_T_R);
	GPIO_GpioClearInterruptFlags(GPIO2, 1<<TASTER_B_L);
	GPIO_GpioClearInterruptFlags(GPIO2, 1<<TASTER_B_R);
}

/* GPIO3_IRQn interrupt handler */
extern "C" void GPIO3_IRQHANDLER(void)
{
	uint32_t hit_flag = GPIO_GpioGetInterruptFlags(GPIO3);

	if((hit_flag>>NULL_TRIGGER_PIN) == 1)
	{
		NULL_flag = true;
	}
	GPIO_GpioClearInterruptFlags(NULL_TRIGGER_GPIO, 1<<NULL_TRIGGER_PIN);
}

// returns a "random" number
uint8_t get_rand_num()
{
    srand(SysTick->VAL%65535);
    return (rand()%12 + 1);
}

// Interrupt for SysTick
extern "C" void SysTick_Handler(void)
{
	tick_count++;
}

// Calculates the time needed for a specific function
uint32_t calc_time_ms()
{
	uint32_t erg = 0;
	if (tick_end >= tick_start)
	{
		erg = tick_end - tick_start;
	}
	else
	{
		erg = (0xFFFFFFFF - tick_start) + tick_end;
	}
	return erg;
}


/*
 * @brief   Application entry point.
 */
int main(void)
{
	char buf_1[] = "Automatic (intern)";
	char buf_2[] = "external_PC USB";
	char buf_e[] = "err in Sensor-Config";

	uint32_t time = 0;

    BOARD_InitBootPins();
    BOARD_InitBootClocks();
    BOARD_InitBootPeripherals();

    SysTick_Config(SystemCoreClock/1000);

    GPIO_PinWrite(MOTOR_EN_GPIO, MOTOR_EN_PIN, M_ENABLE);

#ifdef STEINBRECHER
    tick_start = tick_count;
    while(time < 2000)
    {
    	tick_end = tick_count;
    	time = calc_time_ms();
    }
#endif

	config_motor();

    ssd1309_Init();
    ssd1309_Fill(Black);
    ssd1309_UpdateScreen();

    if (!tcs.init())
    {
    	ssd1309_SetCursor(2,3);
    	ssd1309_WriteString(buf_e,Font_7x10, White);
    }
    else
    {
    	ssd1309_SetCursor(2,3);
    	ssd1309_WriteString(buf_1,Font_7x10, White);
    	ssd1309_SetCursor(2,50);
    	ssd1309_WriteString(buf_2,Font_7x10, White);
    }
    ssd1309_UpdateScreen();

    tcs.write8(TCS34725_PERS, TCS34725_PERS_NONE);
    tcs.setInterrupt(true);

#ifdef STEINBRECHER
    SW_flag_TL = true;
#endif

	while(true)
	{
		// State-Machine
		super_machine();
	}
    return 0 ;
}

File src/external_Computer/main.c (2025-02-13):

/*
*   Gerrit Hinrichs 01.2025
*   github.com/snech99
*
*   Cube_Solver_Robot
*   main-file for the USB Communication
*/
#include "serial.h"

int main(int argc, char *argv[]) 
{
  char input[3] = {};
  int a = 0;

  //Usage
  if (argc != 2) 
  {
      fprintf(stderr, "Usage: %s <python_script_name>\n", argv[0]);
      return 1;
  }
    
  char *script_name = argv[1];
  int serial_port = open("/dev/ttyUSB0", O_RDWR);

  //Configurate the USB connection with err handling
  if(config_serial(&serial_port) != 0)
  {
    printf("Error in tty config\n");
    return 1;
  };

  int pos = 0;
  int cube_buf [54] = {};
  int erg_buf[1024] = {};
  char buf_solve[1033] = {};
  char read_buf[61] = {};
  char buf_busy[1] = {};

  char buf_read[] = {'$','r','e','a','d','_','c','o','l','o','r','!','%'};
  char buf_send[] = {'$','s','e','n','d','_','c','u','b','e','!','%'};
  char buf_rand[] = {'$','r','a','n','d','o','m','!','%'};
  char buf_change[] = {'$','c','h','a','n','g','e','!','%'};

  buf_solve[0] = '$';
  buf_solve[1] = 's';
  buf_solve[2] = 'o';
  buf_solve[3] = 'l';
  buf_solve[4] = 'v';
  buf_solve[5] = 'e';
  buf_solve[6] = '!';
  buf_solve[1031] = 0;
  buf_solve[1032] = '%';

  printf("Cube scanning: 1\nGet the Cube from Robot: 2\nShow the Cube: 3\nPython-Script: 4\nSend moves and solve: 5\n20 random moves: 6\nChange Cube: 7\nEnd program: 8\n");

  //Super-loop with switch() for the commands
  while(1)
  {
    if(fgets(input, sizeof(input), stdin) != NULL)
    {

      a = atoi(input);

      if (a < 1 || a > 8) 
      {
          printf("Invalid Number! It must be between 1 and 8.\n");
      }

      //Switch() with all the possible Commands for the Robot
      switch(input[0])
      { 
        // Scan Cube
        case '1': write(serial_port, buf_read, sizeof(buf_read));
                  printf("Scanning the Cube...\n");
                  read(serial_port, buf_busy, sizeof(buf_busy));
                  if(buf_busy[0] == 1)
                  {
                    printf("Done with scanning!\n");
                  }
                  else
                  {
                    printf("Error: Handshake Scanning\n");
                  }

                  printf("\n");
                  printf("Cube scanning: 1\nGet the Cube from Robot: 2\nShow the Cube: 3\nPython-Script: 4\nSend moves and solve: 5\n20 random moves: 6\nChange Cube: 7\nEnd program: 8\n");
                  break;

        // Receive the scanned Cube
        case '2': write(serial_port, buf_send, sizeof(buf_send));
                  read(serial_port, read_buf, sizeof(read_buf));   
              
                  for(int i=0; i<54; i++)
                  {
                    cube_buf[i] = (int)read_buf[i+6];
                  } 

                  if(cube_buf[0] == 0)
                  {
                    printf("Error due reading or no Cube\n");
                  }
                  else 
                  {
                    printf("Cube received!\n");
                  }  

                  read(serial_port, buf_busy, sizeof(buf_busy));

                  printf("\n");
                  printf("Cube scanning: 1\nGet the Cube from Robot: 2\nShow the Cube: 3\nPython-Script: 4\nSend moves and solve: 5\n20 random moves: 6\nChange Cube: 7\nEnd program: 8\n");
                  break;

        // print the received Cube
        case '3': pos = 0;
                  if(cube_buf[0] == 0)
                  {
                      printf("There is no Cube or Error during the scan\n");
                      break;
                  }

                  printf("\n");
                  for(int k=0; k<6; k++)
                  {
                    for(int l=0; l<3; l++)
                    {
                      for(int j=0; j<3; j++)
                      {
                        printf("%d ",cube_buf[pos]);
                        pos++;
                      }
                      printf("\n");
                    }
                    printf("\n");
                  }
                  
                  printf("\n");
                  printf("Cube scanning: 1\nGet the Cube from Robot: 2\nShow the Cube: 3\nPython-Script: 4\nSend moves and solve: 5\n20 random moves: 6\nChange Cube: 7\nEnd program: 8\n");
                  break;

        // Start the Python-Script for Calculation
        case '4': for(int i=0; i<1024; i++)
                  {
                    erg_buf[i] = 0;
                  }

                  printf("Starting Python-Script\n");
                  if( fork_and_send(cube_buf, erg_buf, script_name) != 0)
                  {
                    printf("Error in fork!\n");
                  } 
                  printf("Calculation in Python done!\n");
                
                  for (int i = 0; i < 1024; i++) 
                  {
                    //printf("%d ", erg_buf[i]);
                    buf_solve[i+7] = erg_buf[i];
                  } 

                  printf("\n");
                  printf("Cube scanning: 1\nGet the Cube from Robot: 2\nShow the Cube: 3\nPython-Script: 4\nSend moves and solve: 5\n20 random moves: 6\nChange Cube: 7\nEnd program: 8\n");
                  break;

        // Send the move_array to the Robot
        case '5': write(serial_port, buf_solve, sizeof(buf_solve));
                  printf("Robot is moving ..\n");
                  read(serial_port, buf_busy, sizeof(buf_busy));
                  if(buf_busy[0] == 1)
                  {
                    printf("Solved\n");
                  }
                  else
                  {
                    printf("Error: Handshake Solve\n");
                  }

                  printf("\n");
                  printf("Cube scanning: 1\nGet the Cube from Robot: 2\nShow the Cube: 3\nPython-Script: 4\nSend moves and solve: 5\n20 random moves: 6\nChange Cube: 7\nEnd program: 8\n");                           
                  break;

        // 20 random moves
        case '6': write(serial_port, buf_rand, sizeof(buf_rand));
                  printf("Cube is doing random moves..\n");
                  read(serial_port, buf_busy, sizeof(buf_busy));
                  if(buf_busy[0] == 1)
                  {
                    printf("Done twisting!\n");
                  }
                  else
                  {
                    printf("Error: Handshake random\n");
                  }
                  
                  for (int i=0; i<54; i++)
                  {
                    cube_buf[i] = 0;
                  }
                  printf("\n");
                  printf("Cube scanning: 1\nGet the Cube from Robot: 2\nShow the Cube: 3\nPython-Script: 4\nSend moves and solve: 5\n20 random moves: 6\nChange Cube: 7\nEnd program: 8\n");
                  break;
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

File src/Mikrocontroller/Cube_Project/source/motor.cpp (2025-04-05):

/*
*   Gerrit Hinrichs 01.2025
*   github.com/snech99
*
*   Cube_Solver_Robot
*   Functions for the Servo and Steppers
*/
#include "Cube_Project.h"

// Configuration for the six Steppers
void config_motor()
{
	uint8_t config_count = 0;
	long int back_count = 0;
	uint32_t time = 0;

	move_servo(18);
	while( GPIO_PinRead(NULL_TRIGGER_GPIO, NULL_TRIGGER_PIN) == 0)
	{
		move_motor(1, 250);
		move_motor(2, 250);
		move_motor(3, 250);
		move_motor(4, 250);
		move_motor(5, 250);
		move_motor(6, 250);
	}

	PWM_flanke_count = 5;
	PWM_SetupPwm(FLEXPWM0_PERIPHERAL, FLEXPWM0_ALL_PWM, FLEXPWM0_ALL_PWM_pwm_function_config, 1U, kPWM_SignedCenterAligned,
						500, FLEXPWM0_ALL_PWM_SM_CLK_SOURCE_FREQ_HZ);

	FLEXPWM0_PERIPHERAL->MCTRL |= PWM_MCTRL_LDOK(kPWM_Control_Module_0);
	FLEXPWM0_PERIPHERAL->MCTRL |= PWM_MCTRL_RUN(kPWM_Control_Module_0);

	pwm_busy_flag = true;

	while(pwm_busy_flag)
	{

	}

	for(uint8_t i=1; i<=6; i++)
	{

#ifdef KRUEGER
		switch (i)
		{
			case 1: 	GPIO_PinWrite(DIR_WHITE_GPIO, DIR_WHITE_PIN, 0);
						GPIO_PinWrite(EN_WHITE_GPIO, EN_WHITE_PIN, 1);
						config_count = 21;
						break;

			case 2:		GPIO_PinWrite(DIR_YELLOW_GPIO, DIR_YELLOW_PIN, 1);
						GPIO_PinWrite(EN_YELLOW_GPIO, EN_YELLOW_PIN, 1);
						config_count = 118;
						break;

			case 3:		GPIO_PinWrite(DIR_RED_GPIO, DIR_RED_PIN, 0);
						GPIO_PinWrite(EN_RED_GPIO, EN_RED_PIN, 1);
						config_count = 19;
						break;

			case 4:		GPIO_PinWrite(DIR_GREEN_GPIO, DIR_GREEN_PIN, 0);
						GPIO_PinWrite(EN_GREEN_GPIO, EN_GREEN_PIN, 1);
						config_count = 68;
						break;

			case 5:		GPIO_PinWrite(DIR_ORANGE_GPIO, DIR_ORANGE_PIN, 1);
						GPIO_PinWrite(EN_ORANGE_GPIO, EN_ORANGE_PIN, 1);
						config_count = 124;
						break;

			case 6:		GPIO_PinWrite(DIR_BLUE_GPIO, DIR_BLUE_PIN, 0);
						GPIO_PinWrite(EN_BLUE_GPIO, EN_BLUE_PIN, 1);
						config_count = 63;
						break;
			default:
				break;
		}
#endif

#ifdef STEINBRECHER
		switch (i)
		{
			case 1: 	GPIO_PinWrite(DIR_WHITE_GPIO, DIR_WHITE_PIN, 1);
						GPIO_PinWrite(EN_WHITE_GPIO, EN_WHITE_PIN, 1);
						config_count = 35;
						break;

			case 2:		GPIO_PinWrite(DIR_YELLOW_GPIO, DIR_YELLOW_PIN, 0);
						GPIO_PinWrite(EN_YELLOW_GPIO, EN_YELLOW_PIN, 1);
						config_count =10; 
						break;

			case 3:		GPIO_PinWrite(DIR_RED_GPIO, DIR_RED_PIN, 0);
						GPIO_PinWrite(EN_RED_GPIO, EN_RED_PIN, 1);
						config_count = 97; 
						break;

			case 4:		GPIO_PinWrite(DIR_GREEN_GPIO, DIR_GREEN_PIN, 0);
						GPIO_PinWrite(EN_GREEN_GPIO, EN_GREEN_PIN, 1);
						config_count = 15; 
						break;

			case 5:		GPIO_PinWrite(DIR_ORANGE_GPIO, DIR_ORANGE_PIN, 0);
						GPIO_PinWrite(EN_ORANGE_GPIO, EN_ORANGE_PIN, 1);
						config_count = 47; 
						break;

			case 6:		GPIO_PinWrite(DIR_BLUE_GPIO, DIR_BLUE_PIN, 0);
						GPIO_PinWrite(EN_BLUE_GPIO, EN_BLUE_PIN, 1);
						config_count = 17; 
						break;
			default:
				break;
		}
#endif

		PWM_flanke_count = 2000;

		PWM_SetupPwm(FLEXPWM0_PERIPHERAL, FLEXPWM0_ALL_PWM, FLEXPWM0_ALL_PWM_pwm_function_config, 1U, kPWM_SignedCenterAligned,
							1000, FLEXPWM0_ALL_PWM_SM_CLK_SOURCE_FREQ_HZ);

		FLEXPWM0_PERIPHERAL->MCTRL |= PWM_MCTRL_LDOK(kPWM_Control_Module_0);
		FLEXPWM0_PERIPHERAL->MCTRL |= PWM_MCTRL_RUN(kPWM_Control_Module_0);

		tick_start = tick_count;

		NULL_flag = false;
		while(!NULL_flag)
		{

		}

		FLEXPWM0_PERIPHERAL->MCTRL &= ~(PWM_MCTRL_RUN(kPWM_Control_Module_0));

		PWM_flanke_count = config_count;

		PWM_SetupPwm(FLEXPWM0_PERIPHERAL, FLEXPWM0_ALL_PWM, FLEXPWM0_ALL_PWM_pwm_function_config, 1U, kPWM_SignedCenterAligned,
									1000, FLEXPWM0_ALL_PWM_SM_CLK_SOURCE_FREQ_HZ);

		FLEXPWM0_PERIPHERAL->MCTRL |= PWM_MCTRL_LDOK(kPWM_Control_Module_0);
		FLEXPWM0_PERIPHERAL->MCTRL |= PWM_MCTRL_RUN(kPWM_Control_Module_0);

		pwm_busy_flag = true;

		while(pwm_busy_flag)
		{

		}

		tick_end = tick_count;
		time = calc_time_ms();

		float tmp = (float)time/(float)250;

		back_count = lroundf(tmp)*250;

		FLEXPWM0_PERIPHERAL->MCTRL &= ~(PWM_MCTRL_RUN(kPWM_Control_Module_0));

#ifdef KRUEGER
		switch (i)
		{
			case 1: 	GPIO_PinWrite(DIR_WHITE_GPIO, DIR_WHITE_PIN, 1);
						break;

			case 2:		GPIO_PinWrite(DIR_YELLOW_GPIO, DIR_YELLOW_PIN, 0);
						break;

			case 3:		GPIO_PinWrite(DIR_RED_GPIO, DIR_RED_PIN, 1);
						break;

			case 4:		GPIO_PinWrite(DIR_GREEN_GPIO, DIR_GREEN_PIN, 1);
						break;

			case 5:		GPIO_PinWrite(DIR_ORANGE_GPIO, DIR_ORANGE_PIN, 0);
						break;

			case 6:		GPIO_PinWrite(DIR_BLUE_GPIO, DIR_BLUE_PIN, 1);
						break;
			default:
						break;
		}
#endif

#ifdef STEINBRECHER
		switch (i)
		{
			case 1: 	GPIO_PinWrite(DIR_WHITE_GPIO, DIR_WHITE_PIN, 0);
						break;

			case 2:		GPIO_PinWrite(DIR_YELLOW_GPIO, DIR_YELLOW_PIN, 1);
						break;

			case 3:		GPIO_PinWrite(DIR_RED_GPIO, DIR_RED_PIN, 1);
						break;

			case 4:		GPIO_PinWrite(DIR_GREEN_GPIO, DIR_GREEN_PIN, 1);
						break;

			case 5:		GPIO_PinWrite(DIR_ORANGE_GPIO, DIR_ORANGE_PIN, 1);
						break;

			case 6:		GPIO_PinWrite(DIR_BLUE_GPIO, DIR_BLUE_PIN, 1);
						break;
			default:
						break;
		}
#endif

		PWM_flanke_count = (uint16_t)back_count;

		PWM_SetupPwm(FLEXPWM0_PERIPHERAL, FLEXPWM0_ALL_PWM, FLEXPWM0_ALL_PWM_pwm_function_config, 1U, kPWM_SignedCenterAligned,
									1000, FLEXPWM0_ALL_PWM_SM_CLK_SOURCE_FREQ_HZ);

		FLEXPWM0_PERIPHERAL->MCTRL |= PWM_MCTRL_LDOK(kPWM_Control_Module_0);
		FLEXPWM0_PERIPHERAL->MCTRL |= PWM_MCTRL_RUN(kPWM_Control_Module_0);

		pwm_busy_flag = true;
		while(pwm_busy_flag)
		{

		}

	 	GPIO_PinWrite(EN_WHITE_GPIO, EN_WHITE_PIN, 0);
		GPIO_PinWrite(EN_YELLOW_GPIO, EN_YELLOW_PIN, 0);
		GPIO_PinWrite(EN_RED_GPIO, EN_RED_PIN, 0);
		GPIO_PinWrite(EN_GREEN_GPIO, EN_GREEN_PIN, 0);
		GPIO_PinWrite(EN_ORANGE_GPIO, EN_ORANGE_PIN, 0);
		GPIO_PinWrite(EN_BLUE_GPIO, EN_BLUE_PIN, 0);
	}
}
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

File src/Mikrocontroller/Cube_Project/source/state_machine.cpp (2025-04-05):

/*
*   Gerrit Hinrichs 01.2025
*   github.com/snech99
*
*   Cube_Solver_Robot
*   State-Machine and all important functions
*/
#include "Cube_Project.h"
#include "state_machine.h"
#include "Adafruit_TCS34725.h"
#include "solver_algorithmus_new\example_cubes.h"
#include "solver_algorithmus_new\do_magic.h"
#include <ssd1309/ssd1309.h>

Adafruit_TCS34725 tcs = Adafruit_TCS34725(TCS34725_INTEGRATIONTIME_240MS, TCS34725_GAIN_1X);
State_t CURRENT_STATE = config;
message msg;
int move_array_final [200] = {};
char buf_back[] = "back";
uint8_t busy_msg[1] = {1};

int cube_array[54] = {};

int manual_state_flag = 0;

uint8_t cube_message[61];

// State-Machine struct with all combinations
State_Transition transitionTable[] =
{
	{config, Taster_T_L, idle_auto, back_to_auto},
	{config, Taster_B_L, idle_man, config_to_man_Handler},
	{idle_auto, Taster_T_L, random_auto, auto_to_random_Handler},
	{idle_auto, Taster_B_L, read_color_auto, auto_to_read_color_Handler},
	{idle_auto, Taster_T_R, solve_auto, auto_to_solve_Handler},
	{idle_auto, Taster_B_R, change_cube, auto_to_change_Handler},
	{solve_auto, Taster_B_R, idle_auto, back_to_auto},
	{solve_auto, Taster_T_L, fast, solve_to_fast_Handler},
	{solve_auto, Taster_B_L, slow, solve_to_slow_Handler},
	{random_auto, Taster_B_R, idle_auto, back_to_auto},
	{read_color_auto, Taster_B_R, idle_auto, back_to_auto},
	{fast, Taster_B_R, idle_auto, back_to_auto},
	{slow, Taster_B_R, idle_auto, back_to_auto},
	{change_cube, Taster_B_R, idle_auto, back_to_auto},

	{idle_man, msg_random, idle_man, man_to_random_Handler},
	{idle_man, msg_read_color, idle_man, man_to_read_color_Handler},
	{idle_man, msg_send_cube, idle_man, man_to_send_cube_Handler},
	{idle_man, msg_solve, idle_man, man_to_solve_Handler},
	{idle_man, msg_change, idle_man, man_to_change_Handler},
};

// State-Machine: from config to external_PC
void config_to_man_Handler(void)
{
	manual_state_flag = 1;

	char buf_1[] = "1:Scan Cube";
	char buf_2[] = "2:Send Cube to PC";
	char buf_5[] = "5:Solve";
	char buf_6[] = "6:20 Random moves";
	char buf_7[] = "7:Change Cube";

    ssd1309_Fill(Black);
    ssd1309_UpdateScreen();

	ssd1309_SetCursor(1,1);
	ssd1309_WriteString(buf_1,Font_7x10, White);

	ssd1309_SetCursor(1,13);
	ssd1309_WriteString(buf_2,Font_7x10, White);

	ssd1309_SetCursor(1,25);
	ssd1309_WriteString(buf_5,Font_7x10, White);

	ssd1309_SetCursor(1,37);
	ssd1309_WriteString(buf_6,Font_7x10, White);

	ssd1309_SetCursor(1,49);
	ssd1309_WriteString(buf_7,Font_7x10, White);

	ssd1309_UpdateScreen();
}

// State-Machine: from automatic to random
void auto_to_random_Handler(void)
{
	uint8_t erg = 0;
	uint8_t last = 0;
	uint8_t temp = 0;
	uint8_t pos = 0;

	ssd1309_Fill(Black);
	ssd1309_UpdateScreen();

	while(pos < 20)
	{
		erg = get_rand_num();

		if(erg > 6)
		{
			temp = erg-6;
		}
		else
		{
			temp = erg+6;
		}

		if(temp != last)
		{
			move_motor(erg, 250);
			pos++;
		}
		last = erg;
	}

	for(uint8_t i=0; i<54; i++)
	{
		cube_array[i] = 0;
	}

	ssd1309_Fill(Black);
	ssd1309_UpdateScreen();
	ssd1309_SetCursor(97,51);
	ssd1309_WriteString(buf_back,Font_7x10, White);
	ssd1309_UpdateScreen();
}

// State-Machine: from automatic to Scan Cube
void auto_to_read_color_Handler(void)
{
	GPIO_PinWrite(GPIO2,LED_SWITCH_PIN, 1);

	char buf[] = "scanning ...";
	char buf_e[] = "error";
	char buf_f[] = "correct";

    ssd1309_Fill(Black);
    ssd1309_UpdateScreen();
	ssd1309_SetCursor(20,25);
	ssd1309_WriteString(buf, Font_7x10, White);
    ssd1309_UpdateScreen();

	cube_array [4] = 1;
	cube_array [13] = 3;
	cube_array [22] = 6;
	cube_array [31] = 5;
	cube_array [40] = 4;
	cube_array [49] = 2;

	uint8_t color;
	uint8_t pos_read = 0;

	volatile uint8_t pos_array_read[48] =
	{
			3,6,7,8,5,2,1,0,
			16,17,14,11,10,9,12,15,
			23,20,19,18,21,24,25,26,
			28,27,30,33,34,35,32,29,
			39,42,43,44,41,38,37,36,
			48,51,46,53,50,47,52,45
	};

	for(uint8_t i=0; i<6; i++)
	{
		PWM_ramp_time = RAMP_SHORT;

		move_servo(15);

		for( uint8_t i=0; i<6; i++)
		{
			pwm_servo_busy_flag = true;
			CTIMER_StartTimer(CTIMER2);
			while(pwm_servo_busy_flag)
			{

			}
		}

		for(uint8_t k=0; k<8; k++)
		{
			color = get_color();
			cube_array [pos_array_read[pos_read]] = color;

			/*
			 * uncomment for Debug-Purpose
			while(!SW_flag_BL)
			{

			}
			SW_flag_BL = false;
			*/

			pos_read++;
			move_motor(1, 125);

			for( uint8_t i=0; i<13; i++)
			{
				pwm_servo_busy_flag = true;
				CTIMER_StartTimer(CTIMER2);
				while(pwm_servo_busy_flag)
				{

				}
			}
		}
		PWM_ramp_time = RAMP_LONG;
		move_servo(17);
		change_sides(i);
	}

	GPIO_PinWrite(GPIO2,LED_SWITCH_PIN, 0);
	move_servo(18);

    ssd1309_Fill(Black);
    ssd1309_UpdateScreen();

	if(!check_colors())
	{
		for(uint8_t i=0; i<54; i++)
		{
			cube_array[i] = 0;
		}

		ssd1309_SetCursor(30,20);
		ssd1309_WriteString(buf_e, Font_11x18, White);
	}
	else
	{
		ssd1309_SetCursor(25,20);
		ssd1309_WriteString(buf_f, Font_11x18, White);
	}

	ssd1309_SetCursor(97,51);
	ssd1309_WriteString(buf_back,Font_7x10, White);
	ssd1309_UpdateScreen();
}

// State-Machine: from automatic to solve
void auto_to_solve_Handler(void)
{
	char buf_1[] = "fast";
	char buf_2[] = "slow";
	char buf_5[] = "No Cube";

	for( uint8_t i=0; i<200; i++)
	{
		move_array_final[i]={0};
	}

	if(cube_array[0] == 0)
	{
		ssd1309_Fill(Black);
		ssd1309_UpdateScreen();

		ssd1309_SetCursor(20,20);
		ssd1309_WriteString(buf_5, Font_11x18, White);

		ssd1309_SetCursor(97,51);
		ssd1309_WriteString(buf_back,Font_7x10, White);

		ssd1309_UpdateScreen();
	}
	else
	{
		ssd1309_Fill(Black);
		ssd1309_UpdateScreen();

		do_magic(cube_array, move_array_final);

		ssd1309_SetCursor(2,3);
		ssd1309_WriteString(buf_1,Font_7x10, White);

		ssd1309_SetCursor(2,50);
		ssd1309_WriteString(buf_2,Font_7x10, White);

		ssd1309_SetCursor(97,51);
		ssd1309_WriteString(buf_back,Font_7x10, White);

		ssd1309_UpdateScreen();
	}
}
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

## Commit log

2024-11-29 first big push
    [MCXA153_Solver_Shield.kicad_pcb, MCXA153_Solver_Shield.kicad_sch, SSQ-106-03-T-D.stp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]
2024-12-11 New PCB and cool Stuff
2025-01-08 Adding Boxenstop and Bugfixes in Solver
    [Cube_Project.cpp, Cube_Project.h, motor.cpp]
2025-01-08 Scan without Servo-Movement
2025-01-11 small Bugfix and adding manual
    [main.c]
2025-02-12 changes for Sensor
2025-02-12 adding 3D Model
    [Abdeckung Netzteil klein v2.step, Abdeckung Netzteil v5.step, Abdeckung Sensor v7.step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]
2025-02-12 update PCB
    [MCXA153_Solver_Shield.kicad_pcb, MCXA153_Solver_Shield.kicad_sch]

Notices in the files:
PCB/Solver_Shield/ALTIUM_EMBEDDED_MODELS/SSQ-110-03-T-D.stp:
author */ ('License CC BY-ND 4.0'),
